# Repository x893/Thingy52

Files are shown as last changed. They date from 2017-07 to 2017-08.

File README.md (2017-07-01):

# Nordic Thingy:52 SDK

Welcome to the Nordic Thingy:52 software development kit.
This kit is designed to assist users in developing their own custom firmware for Thingy.
Please see http://www.nordicsemi.com/thingy for the latest news and software releases.

## Prerequisites

The simplest install is achieved by using one of the automated options below.
Before running the scripts, make sure you have the following software installed:
1. Python v2.7.xx or v3.xx.xx avaialble from https://www.python.org/. During the installation there will be a "Customize Python" window. Here, scroll to the bottom and select "Add python.exe to path." Otherwise, use default configurations.
2. Git v2.xx.xx, Available from https://git-scm.com/. Use default configurations.
3. Install GNU ARM embedded toolchain v4.9-2015q3. Avaialble from https://launchpad.net/gcc-arm-embedded/4.9/4.9-2015-q3-update. Use default configurations.
4. Make must be installed and be in system path.

## Setting up repository
### Windows
1. Run `setup_repo.bat`
2. Go to `project/pca20020_s132/armgcc/`
3. Run `make -j`

### Linux/Mac
1. Run `setup_repo.sh`
2. Go to `project/pca20020_s132/armgcc/`
3. Run `make -j`

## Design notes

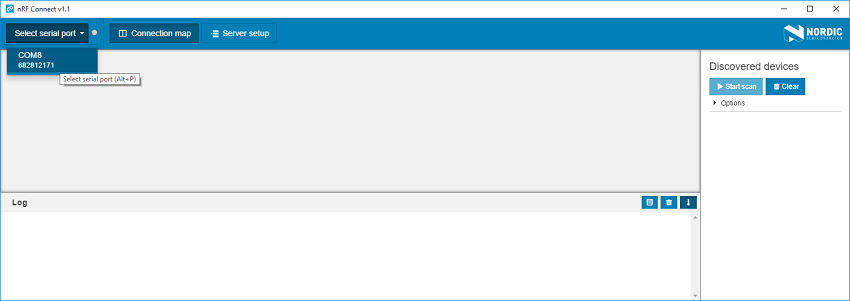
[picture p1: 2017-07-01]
source/doc/dox/pic/nrf_connect_d_1.png

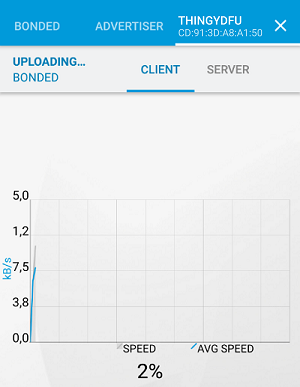
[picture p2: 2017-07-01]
source/doc/dox/pic/dfu_running.PNG

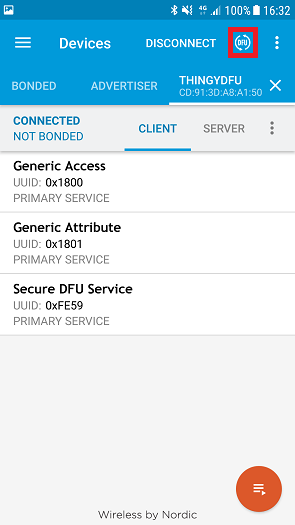
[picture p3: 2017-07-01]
source/doc/dox/pic/dfutarg_connect.png

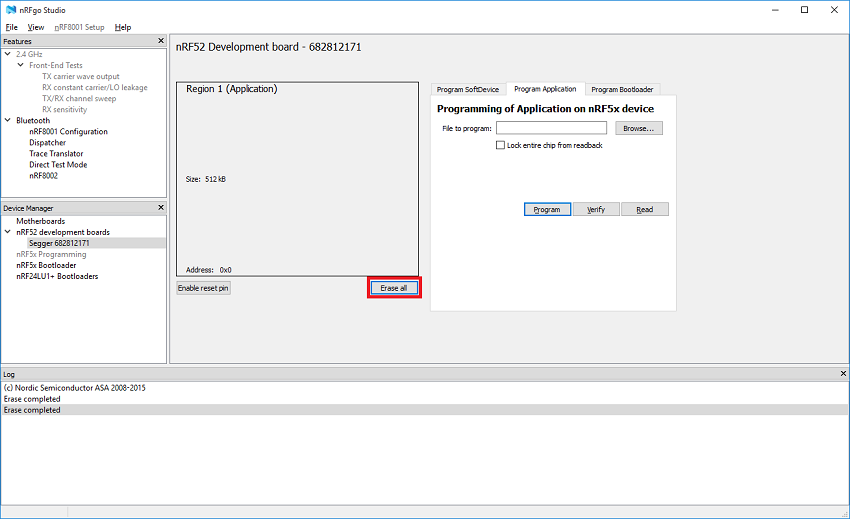
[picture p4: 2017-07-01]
source/doc/dox/pic/erase_all.png

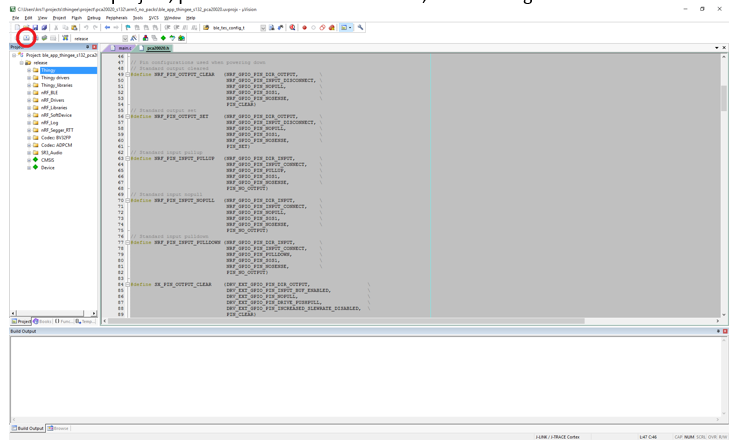
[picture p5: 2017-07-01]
source/doc/dox/pic/keil3.png

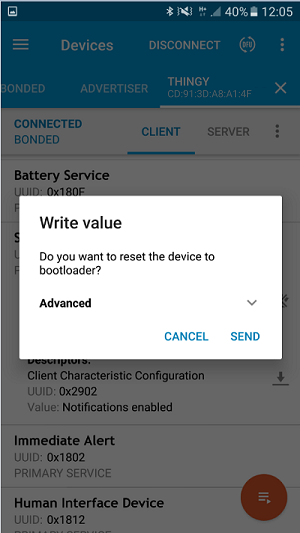
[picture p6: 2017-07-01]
source/doc/dox/pic/bootloader_reset.png

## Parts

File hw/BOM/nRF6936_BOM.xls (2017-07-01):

Bill of material
Kit: | nRF6936 - Thingy:52
Version: | 1.0.0
Designator | Value | Description | Manufacturer | Manufacturer Part Number
Design_1 | PCA20020 - Thingy:52 Board | Circuit board assembly
Design_2 | PCA64110 - NFC Listener-6 antenna | NFC antenna
Battery | Li-ion Polymer | Li-ion Polymer be 8 x 34.5 x 47 mm, 1500mAh | McNair NewPower Co.,Ltd | MLP793444 1440mAh 3.7V
Speaker | Speaker 15x11x3mm | Speaker, SMD, 15.0mm x 11.0mm x 3.0mm, 0Hz-20kHz, 89dB, 8 ohm, 0.7W | BeStar | BMS1511F-11C-08H03P LF

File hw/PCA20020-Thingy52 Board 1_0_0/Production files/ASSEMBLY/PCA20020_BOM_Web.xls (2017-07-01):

Bill of material
Board: | PCA20020
Version: | 1.0.0
Designator | Value | Description | Assembly | Footprint Doc | Manufacturer | Manufacturer Part Number
A1 | 2450AT18B100 | 2.45 GHz chip antenna |  | 2450AT18B100 | Johanson Technology | 2450AT18B100
C1, C2, C11, C12, C32, C33 | 12pF | Capacitor, NP0, ±2% |  | 0402
C3 | 0.8pF | Capacitor, NP0, ±5% |  | 0402
C4, C5, C8, C14, C15, C16, C17, C18, C20, C21, C23, C24, C25, C26, C27, C29, C34, C39 | 100nF | Capacitor, X7R, ±10% |  | 0402
C6 | N.C. | Not mounted | Not mounted | 0402
C7 | 100pF | Capacitor, NP0, ±5% |  | 0402
C9 | 4.7µF | Capacitor, X5R, ±10% |  | 0603
C10, C40, C41 | 1.0µF | Capacitor, X7R, ±10% |  | 0603
C13 | 2.2pF | Capacitor, NP0, ±0.1pF |  | 0402
C19, C30 | 10nF | Capacitor, X7R, ±10% |  | 0402
C22, C31, C38, C42, C44 | 10µF | Capacitor, X5R, ±20% |  | 0603
C28 | 1.0µF | Capacitor, X5R, ±5% |  | 0402
C35 | 150pF | Capacitor, NP0, ±5% |  | 0402
C36 | 330pF | Capacitor, NP0, ±5% |  | 0402
C37 | 220nF | Capacitor, X7R, ±10% |  | 0402
C43, C47 | 22µF | CAP CER 22UF 6.3V 20% X5R 0603 |  | 0603 | Samsung | CL10A226MQ8NRNC
C45, C46 | 270pF | Capacitor, NP0, ±5% |  | 0402
D1, D2 | Zener 2.4V | Diode, Zener, 2.4V, 0.3W |  | SOD-523 | Diodes Incorporated | BZT52C2V4T
FB1 | 600R/0.5A | Ferrite Bead, 600 Ohm @ 100MHz, 500mA, 380 mOhm Max |  | 0603 | Murata | BLM18AG601SN1
J1 | MicroUSB-B | MicroUSB-B-SMT |  | USB-Micro-B-RA-SMD-PiP | Allen Creations Corp. | AJU55-BS2111-L
J2 | HDR-2, 1mm | 1.0mm pitch connector side entry SMD |  | SM02B-SRSS-TB | JST | SM02B-SRSS-TB(LF)(SN)
J3 | FPC 0.5mm RA SMD | 0.5mm FPC, 5P,Right Angle SMT,Double Contact,H=1.2mm,White, Tin plated |  | FPC_05P-0.5mm-RA-SMD | W-CON | 5141-05RZDNWR01
L1, L4 | 3.9nH | Inductor, 170mA, ±0.1nH |  | 0402 | Murata | LQP15MN3N9B02D
L2 | 10µH | Inductor, 80mA, ±10% |  | 0603 | Taiyo Yuden | LBMF1608T100K
L3 | 15nH | Inductor, 320mA, ±5% |  | 0402 | Taiyo Yuden | HK100515NJ-T
L5 | N.C. | Not mounted | Not mounted | 0402
L6 | 220µH | Inductor, ±20%, 200mA, 2.76 Ohm |  | 4040 | Bourns | SRN4026-221M
LD1 | LED RGB | RGB LED 1.60 mm x 1.60 mm SMD |  | LED_RGB_0606 | Lite-On Inc | LTST-C19HE1WT
LD2, LD3 | LED RGB | High brightness, side view RGB LED |  | 6922 | ROHM | MSL0104RGBU1
P1, P2, P3 | Pin List 1x2 | Pin List 1x2, 2.54mm (100mil) | Not mounted | LIST_1x2
P4 | Pin Header 2x10 | Pin Header 2x10, 2.54mm (100mil) | Not mounted | HDR_2x10
P5, P6, P7, P8 | HW4-2.0 | 4 pin, Grove DIP connector | Not mounted | HW4-2.0 | Taifeng | HW4-2.0
P9 | Pin Header 2x5 | Pin Header 2x5, 1.27mm (50mil) |  | HDR_2x5-SMD-1.27mm-ANG | Samtec | FTSH-105-01-L-DH-A-C-TR
Q1, Q4, Q5 | DMC2400UV | Dual N & P Ch MOFET, 1.03A/0.7A, 480mOhm, 450mW |  | SOT-563 | Diodes Incorporated | DMC2400UV
Q2, Q3 | DMP2200UDW | Dual P Ch MOFET, 900mA, 260mOhm, 450mW |  | SOT-363 | Diodes Incorporated | DMP2200UDW
Q6, Q7 | DMN3190LDW | Dual N Ch MOFET, 1A, 190mOhm, 320mW |  | SOT-363 | Diodes Incorporated | DMN3190LDW
R1, R13, R15 | 10k | Resistor, ±1%, 0.063W |  | 0402
R2, R3 | 1M0 | Resistor, ±1%, 0.063W |  | 0402
R4, R7 | 169R | Resistor, ±1%, 0.063W |  | 0402
R5, R8 | 7R15 | Resistor, ±1%, 0.063W |  | 0402
R6, R9 | 11R | Resistor, ±1%, 0.063W |  | 0402
R10 | 100R | Resistor, ±1%, 0.063W |  | 0402
R11, R12 | 39R | Resistor, ±1%, 0.063W |  | 0402
R14, R16 | 18k | Resistor, ±1%, 0.063W |  | 0402
R17 | 27k | Resistor, ±1%, 0.063W |  | 0402
R18 | 15k | Resistor, ±1%, 0.063W |  | 0402
R19 | 10k | THERMISTOR 10K OHM NTC 0402 SMD |  | 0402 | Murata | NCP15XH103F03RC
R20 | 1M5 | Resistor, ±1%, 0.063W |  | 0402
R21 | 180k | Resistor, ±1%, 0.063W |  | 0402
R22, R23, R24, R25 | 4k7 | Resistor, ±1%, 0.063W |  | 0402
R27, R28 | 470R | Resistor, ±1%, 0.063W |  | 0402
R29, R30, R31 | 100k | Resistor, ±1%, 0.063W |  | 0402
SW1 | Switch | SMD slide Switch (ON-ON) |  | Switch-Slide-RA-J-Lead-DPDT-8.5x3.5mm | C&K Components | JS202011JAQN
SW2 | PB SW | Tactile Switch, SPNO, SMD, 160gf, 6.2x6.3x2.5mm |  | Switch-PB-6.2x6.3mm-SMD | Dailywell | TS604VM1-025BR-R
U1 | nRF52832-QFAAB0 | Multi-protocol Bluetooth Low Energy, ANT and 2.4GHz proprietary system-on-chip |  | QFN-48 | Nordic Semiconductor | nRF52832-QFAAB0
U2 | SX1509BIULTRT | IC GPIO EXPANDER I2C 16CH 28QFN |  | QFN-28 | Semtech Corporation | SX1509BIULTRT
U3 | MPU-9250 | 9-axis MotionTracking™ Device |  | QFN-24 | InvenSense | MPU-9250
U4, U10, U12 | NX3DV2567 | Low-ohmic four-pole double-throw analog switch |  | XQFN-16 | NXP Semiconductors | NX3DV2567GU
U5 | LIS2DH12 | 3-axis - ±2g/±4g/±8g/±16g digital output femto accelerometer |  | LGA-12 | STMicroelectronics | LIS2DH12
U6 | LPS22HB | MEMS nano pressure sensor: 260-1260 hPa absolute digital output barometer |  | HLGA-10L | STMicroelectronics | LPS22HB
U7 | HTS221 | Capacitive digital sensor for relative humidity and temperature |  | HLGA-6L | STMicroelectronics | HTS221
U8 | BH1745NUC | Digital 16bit Serial Output Type Color Sensor IC |  | WSON-8 | Rohm Semiconductor | BH1745NUC
U9 | CCS811 | Ultra-low power digital gas sensor for monitoring indoor air quality |  | LGA-10 | Cambridge CMOS Sensors | CCS811
U11 | MP34DB02 | MEMS audio sensor omnidirectional digital microphone |  | RHLGA-4 | STMicroelectronics | MP34DB02
U13, U15 | TCK106AF | 1.0 A Load Switch IC with Slew Rate Control Driver in Small Package |  | SOT-25 | Toshiba | TCK106AF,LF
U14 | XCL210C33 | 3.3V 200mA Inductor Built-in Step-Down “micro DC/DC” Converter |  | CL-2025 | Torex Semiconductor | XCL210C33
U16 | XC6804A4E1 | One Cell Li-ion/Li-polymer Linear Charger IC with Battery Temperature Detection |  | USP-6EL | Torex Semiconductor | XC6804A4E14R-G
X1 | 32MHz | XTAL SMD 2016, 32MHz, Cl=8pF, Tot: ±40ppm |  | XTAL_2016 | Kyocera | CX2016DB32000D0WZRC1
X2 | 32.768kHz | XTAL SMD 2012, 32.768kHz, 9pF, ±20ppm |  | XTAL_2012 | Micro Crystal | CM8V-T1A 32.768KHZ 9PF +/-20PPM TA QC

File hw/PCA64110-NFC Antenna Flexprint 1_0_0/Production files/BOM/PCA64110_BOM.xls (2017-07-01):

Bill of material
PCB: | PCA64110
Version: | 1.0.0
Designator | Value | Description | Footprint Doc | Manufacturer | Manufacturer Part Number

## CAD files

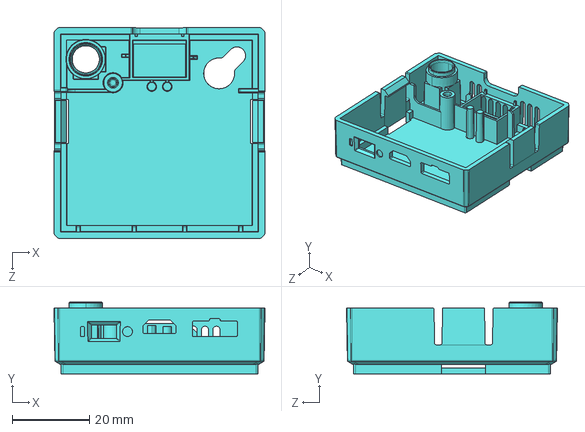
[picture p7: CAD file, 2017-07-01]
hw/CASING/Thingy52_Base.step
54.5 x 18.5 x 54.5 mm

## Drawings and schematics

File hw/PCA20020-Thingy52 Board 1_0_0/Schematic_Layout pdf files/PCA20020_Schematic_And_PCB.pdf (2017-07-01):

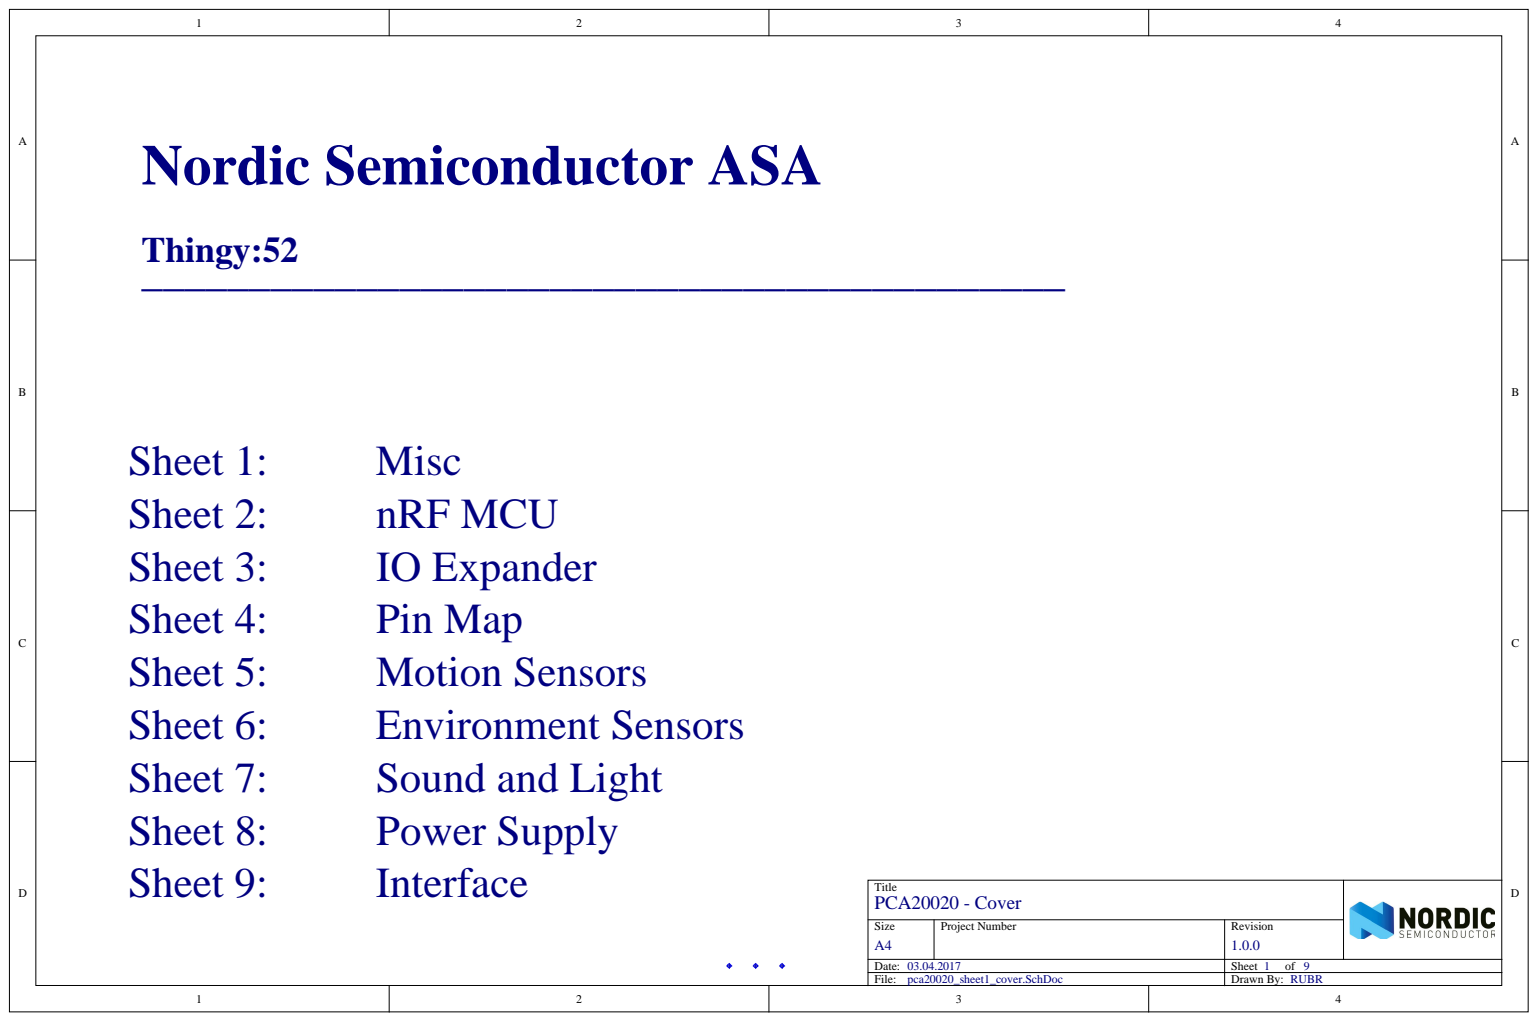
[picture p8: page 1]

Title PCA20020 - Cover

Size A4 | Project Number | Revision 1.0.0

Date: 03.04.2017 | Sheet of
File: pca20020_sheet1_cover.SchDoc | Drawn By: RUBR

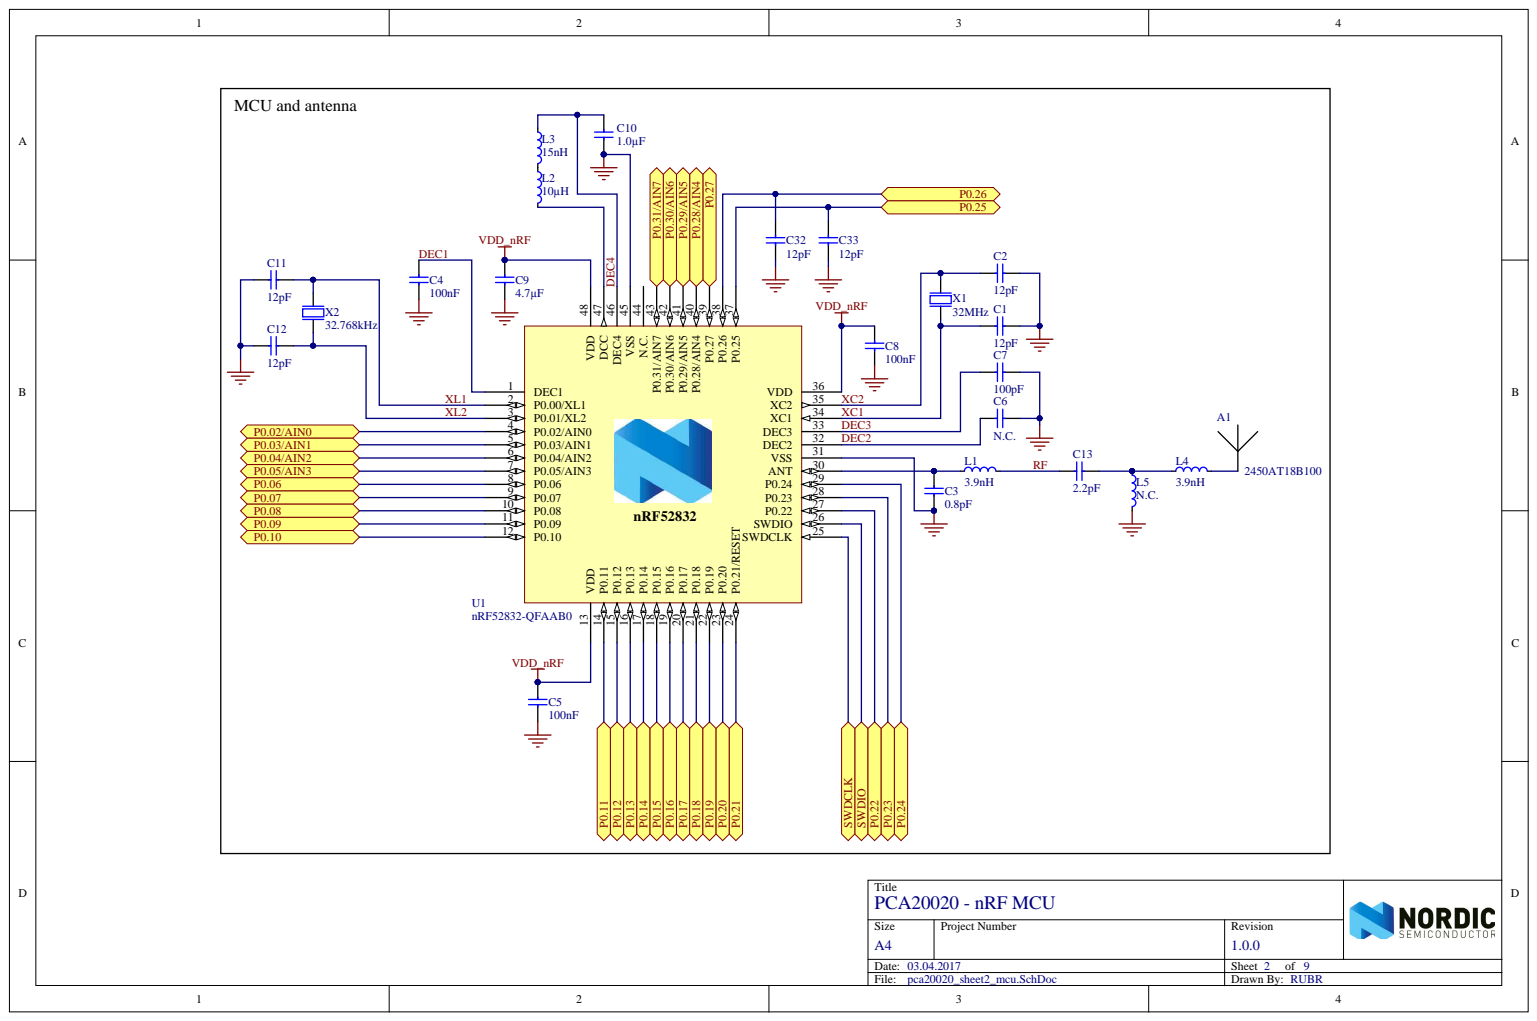
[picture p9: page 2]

P0.02/AIN0 4 P0.03/AIN1 5 P0.04/AIN2 6 P0.05/AIN3 7 P0.06 8 P0.07 9 P0.08 10 P0.09 11 P0.10 12 | DEC3

DEC2

Title PCA20020 - nRF MCU

Size A4 | Project Number | Revision 1.0.0

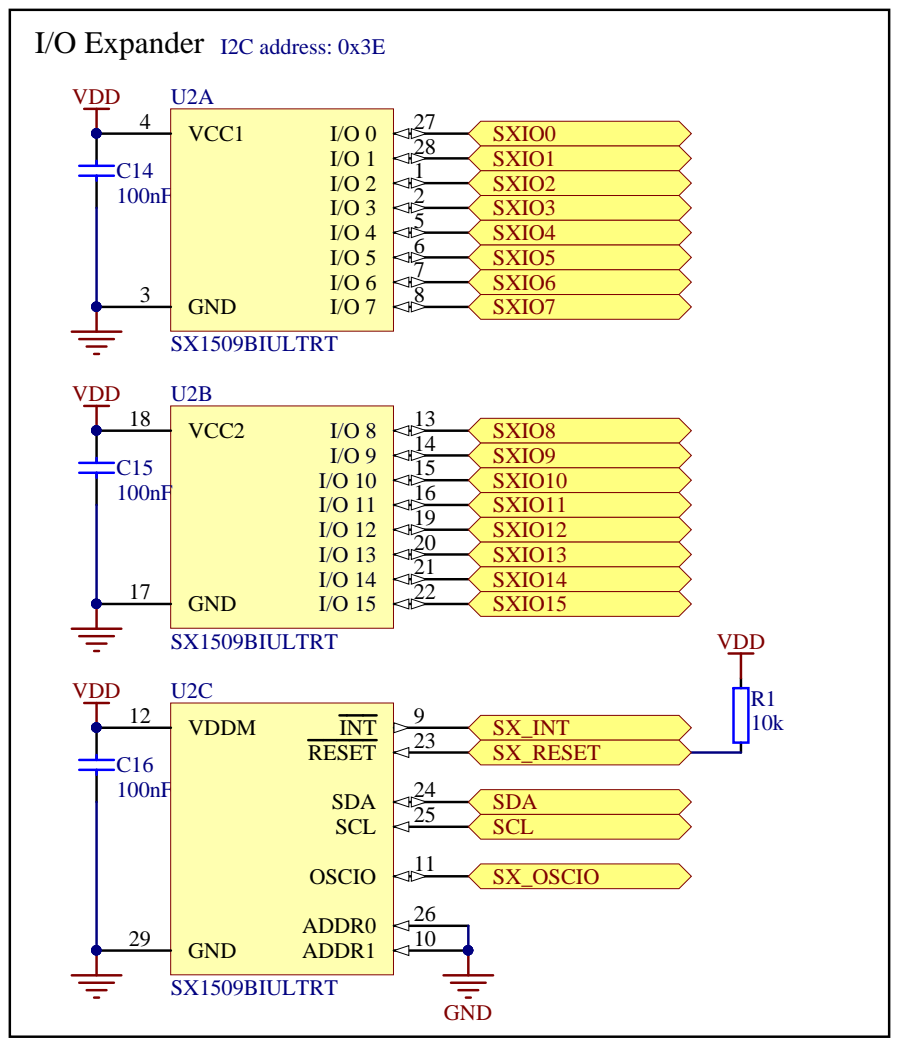
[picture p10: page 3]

Title PCA20020 - IO Expander

Size A4 | Project Number | Revision 1.0.0

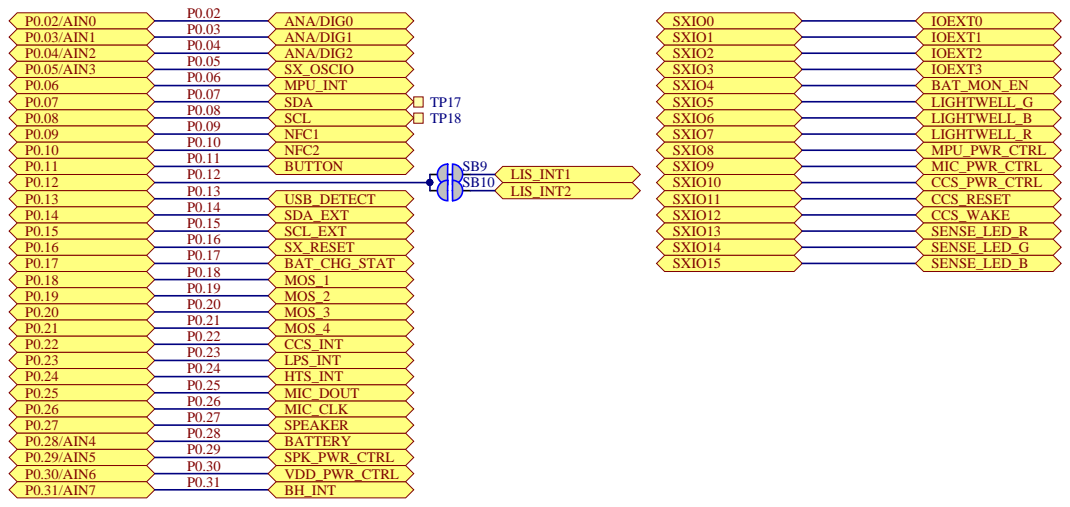
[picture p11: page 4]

Title PCA20020 - nRF Radio

Size A4 | Project Number | Revision 1.0.0

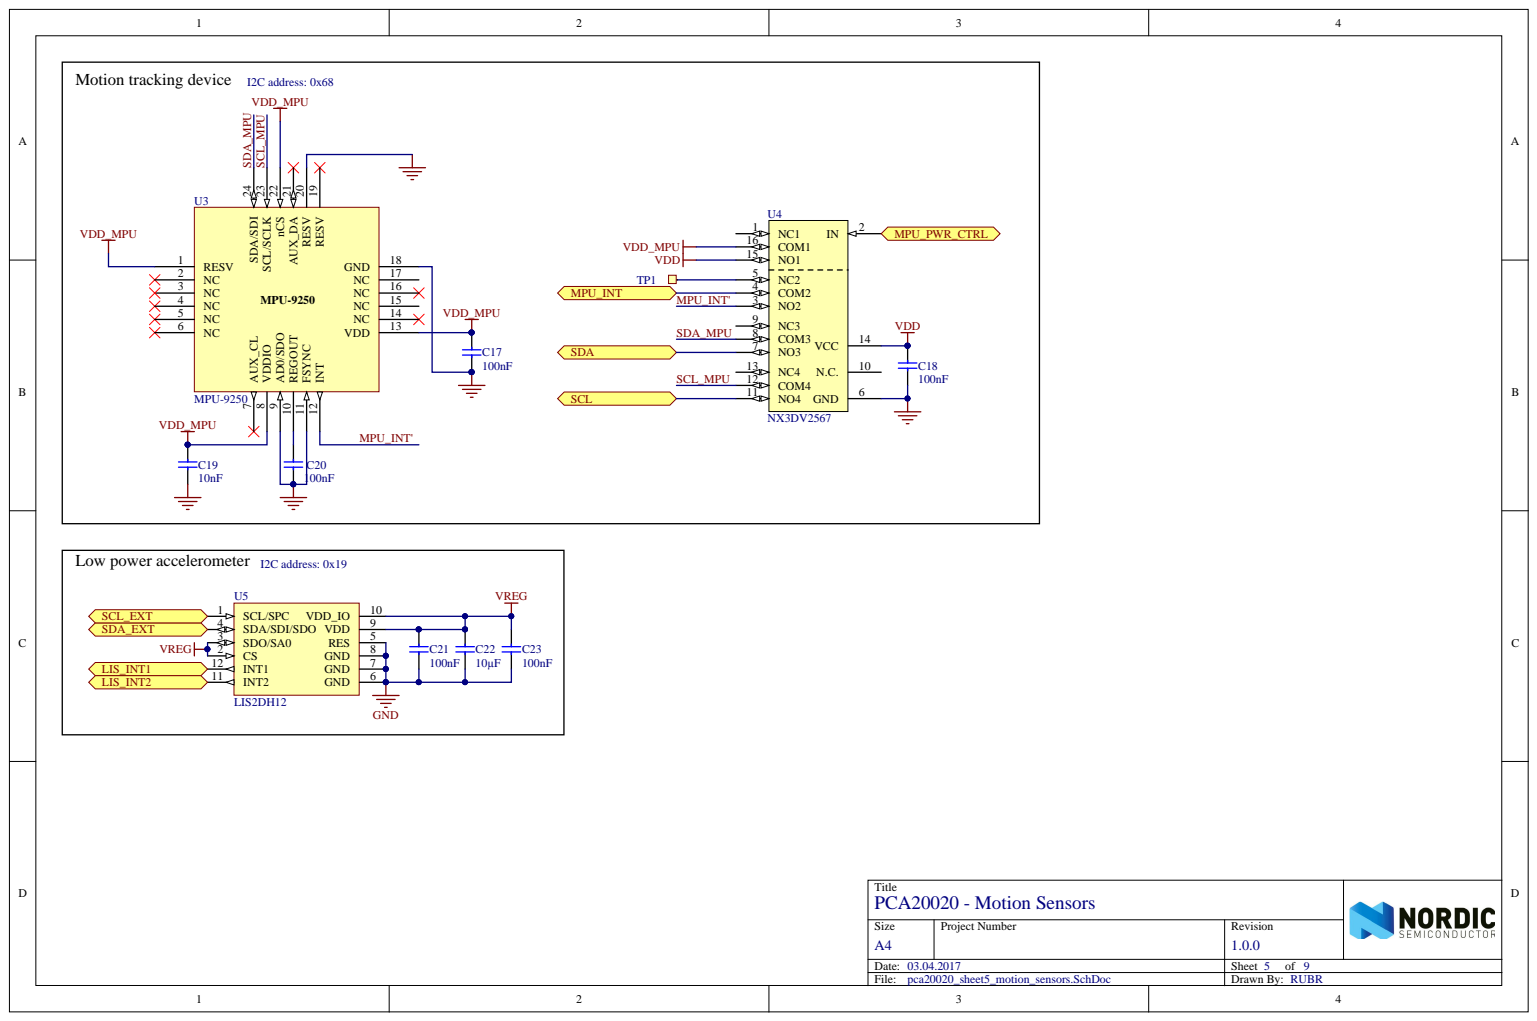
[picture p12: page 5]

Motion tracking device I2C address: 0x68

Title PCA20020 - Motion Sensors

Size A4 | Project Number | Revision 1.0.0

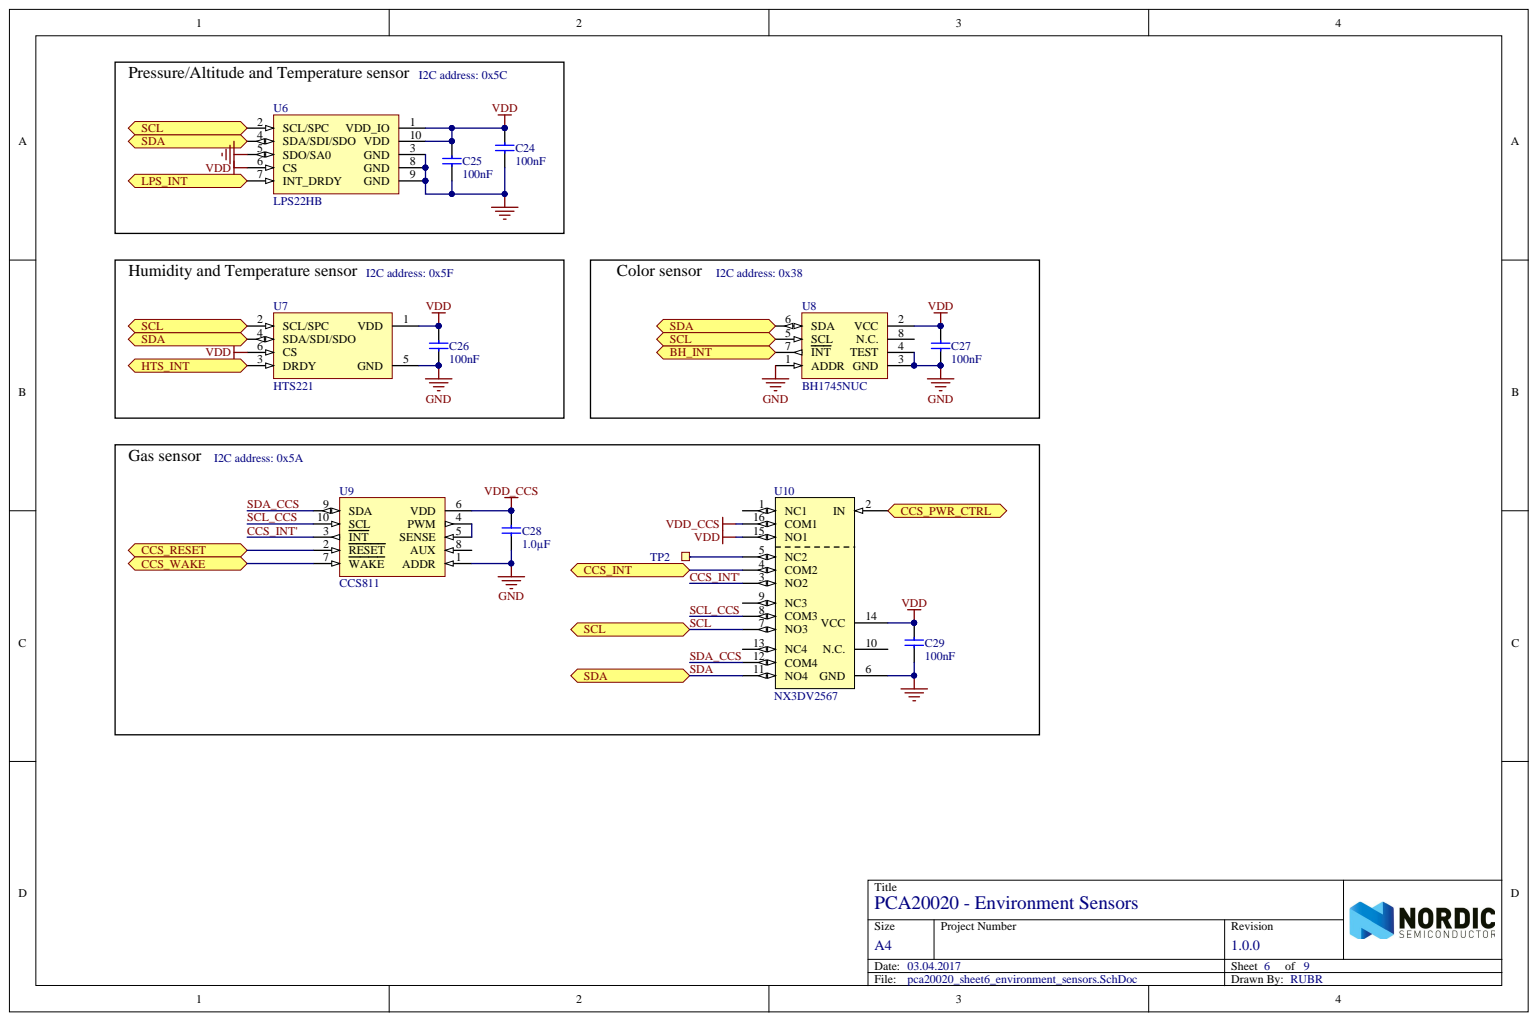
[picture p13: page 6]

Pressure/Altitude and Temperature sensor I2C address: 0x5C

Humidity and Temperature sensor I2C address: 0x5F

Title PCA20020 - Environment Sensors

Size A4 | Project Number | Revision 1.0.0

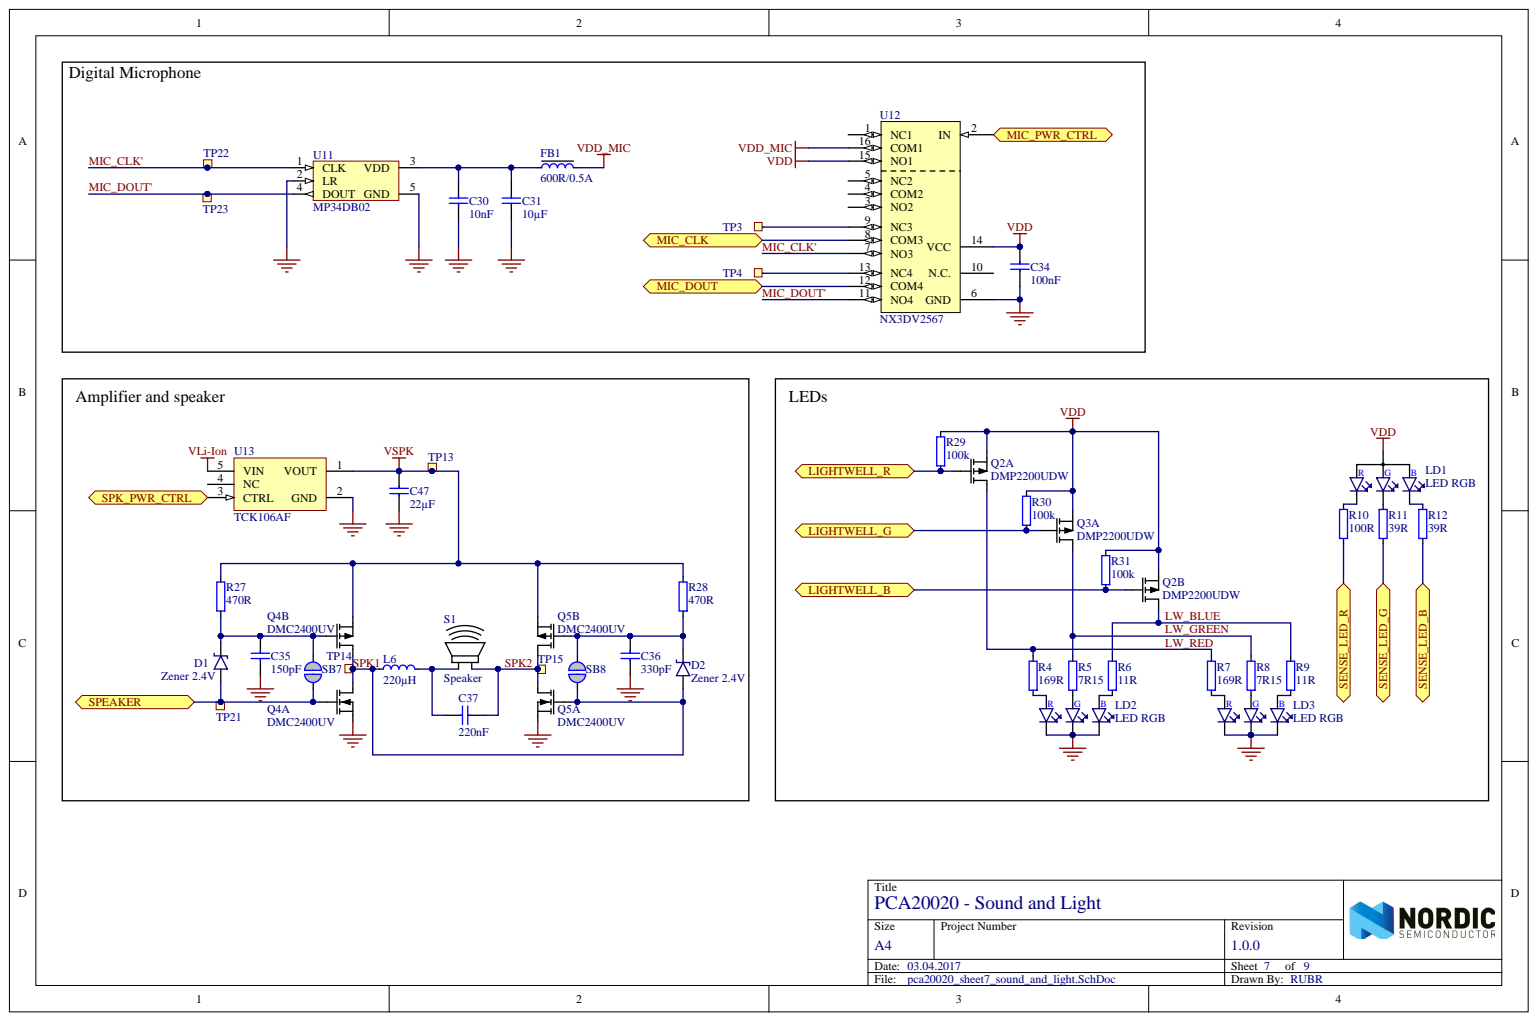
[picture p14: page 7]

LW_RED

LED RGB

Title PCA20020 - Sound and Light

Size A4 | Project Number | Revision 1.0.0

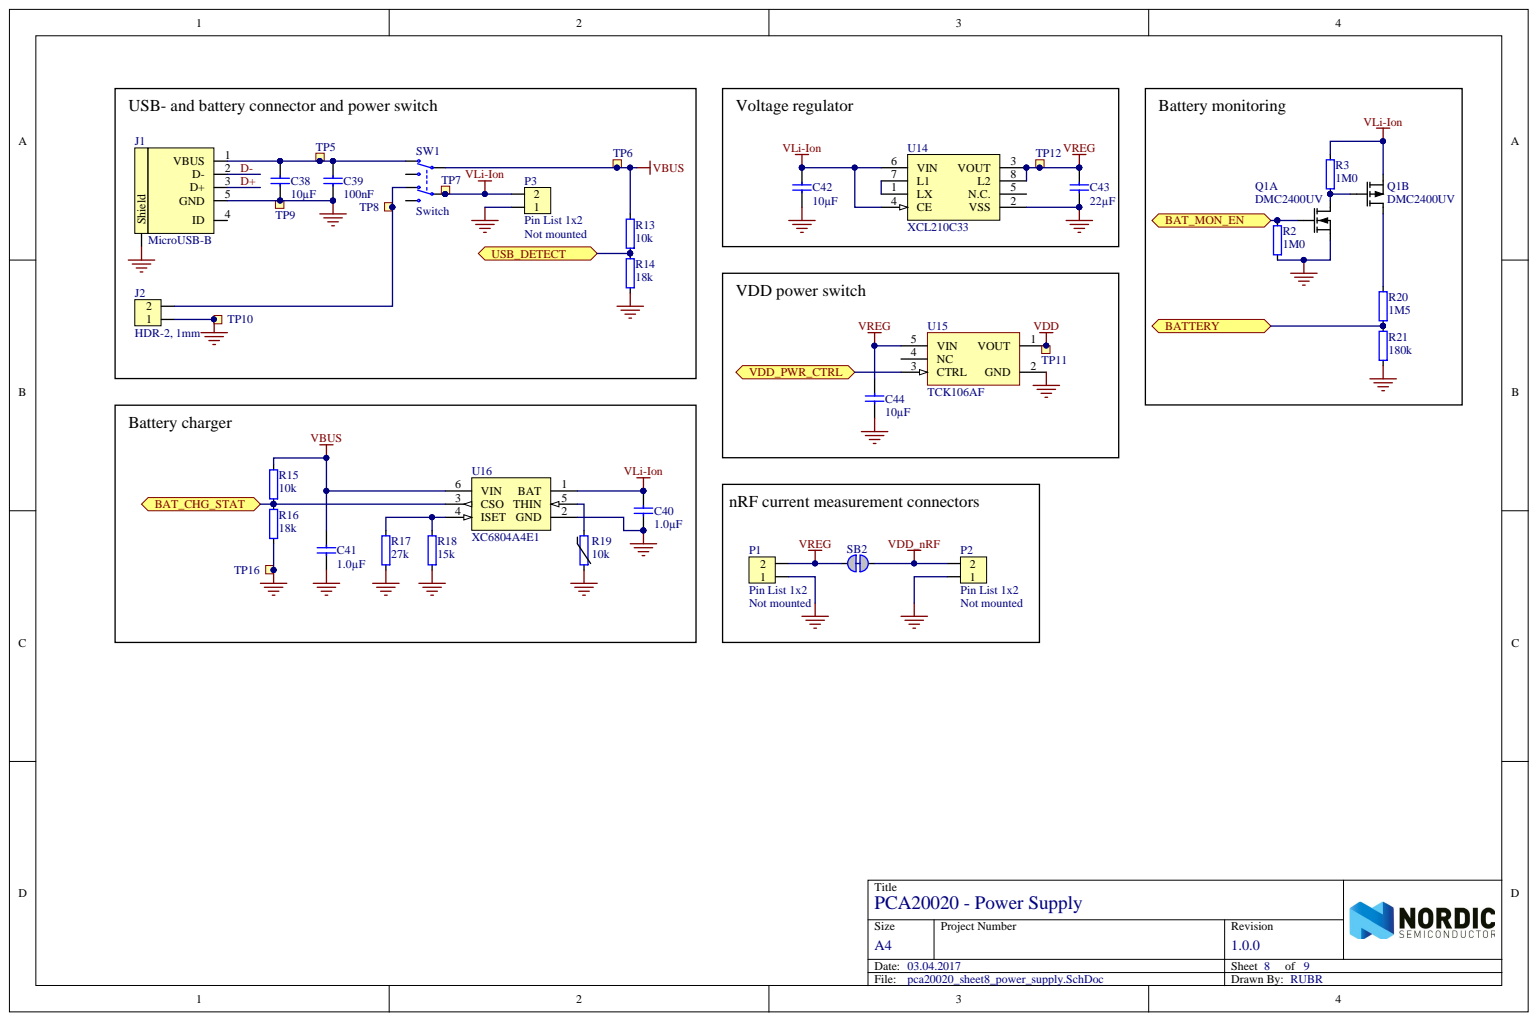
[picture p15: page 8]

USB- and battery connector and power switch

nRF current measurement connectors

Title PCA20020 - Power Supply

Size A4 | Project Number | Revision 1.0.0

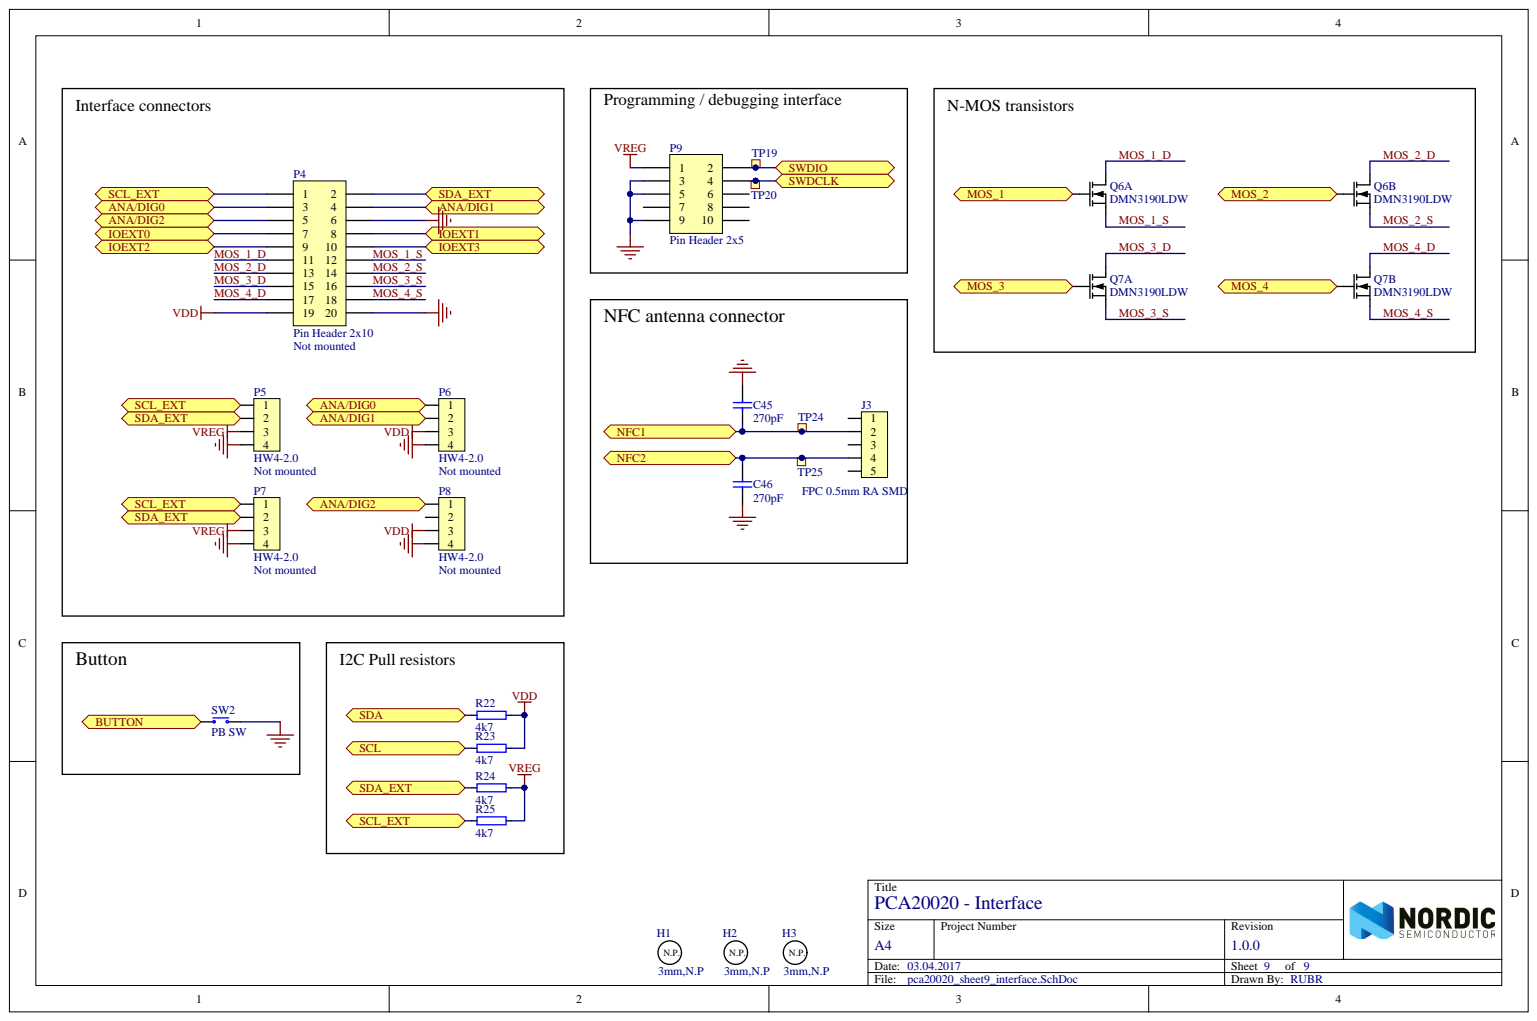
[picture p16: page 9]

Title PCA20020 - Interface

Size A4 | Project Number | Revision 1.0.0

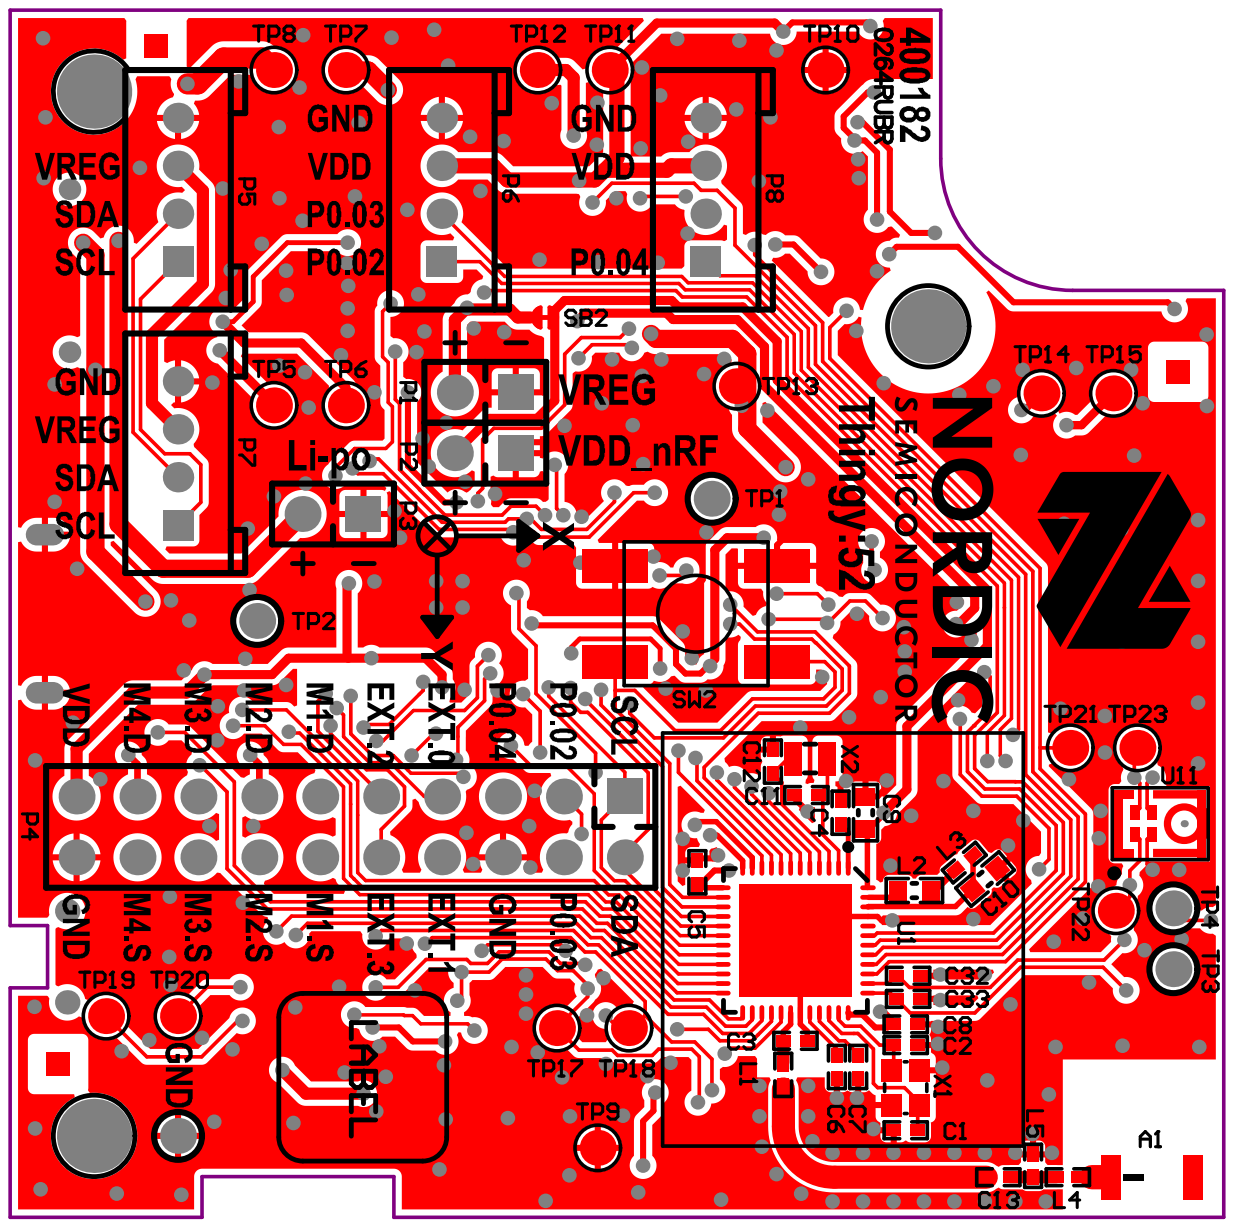
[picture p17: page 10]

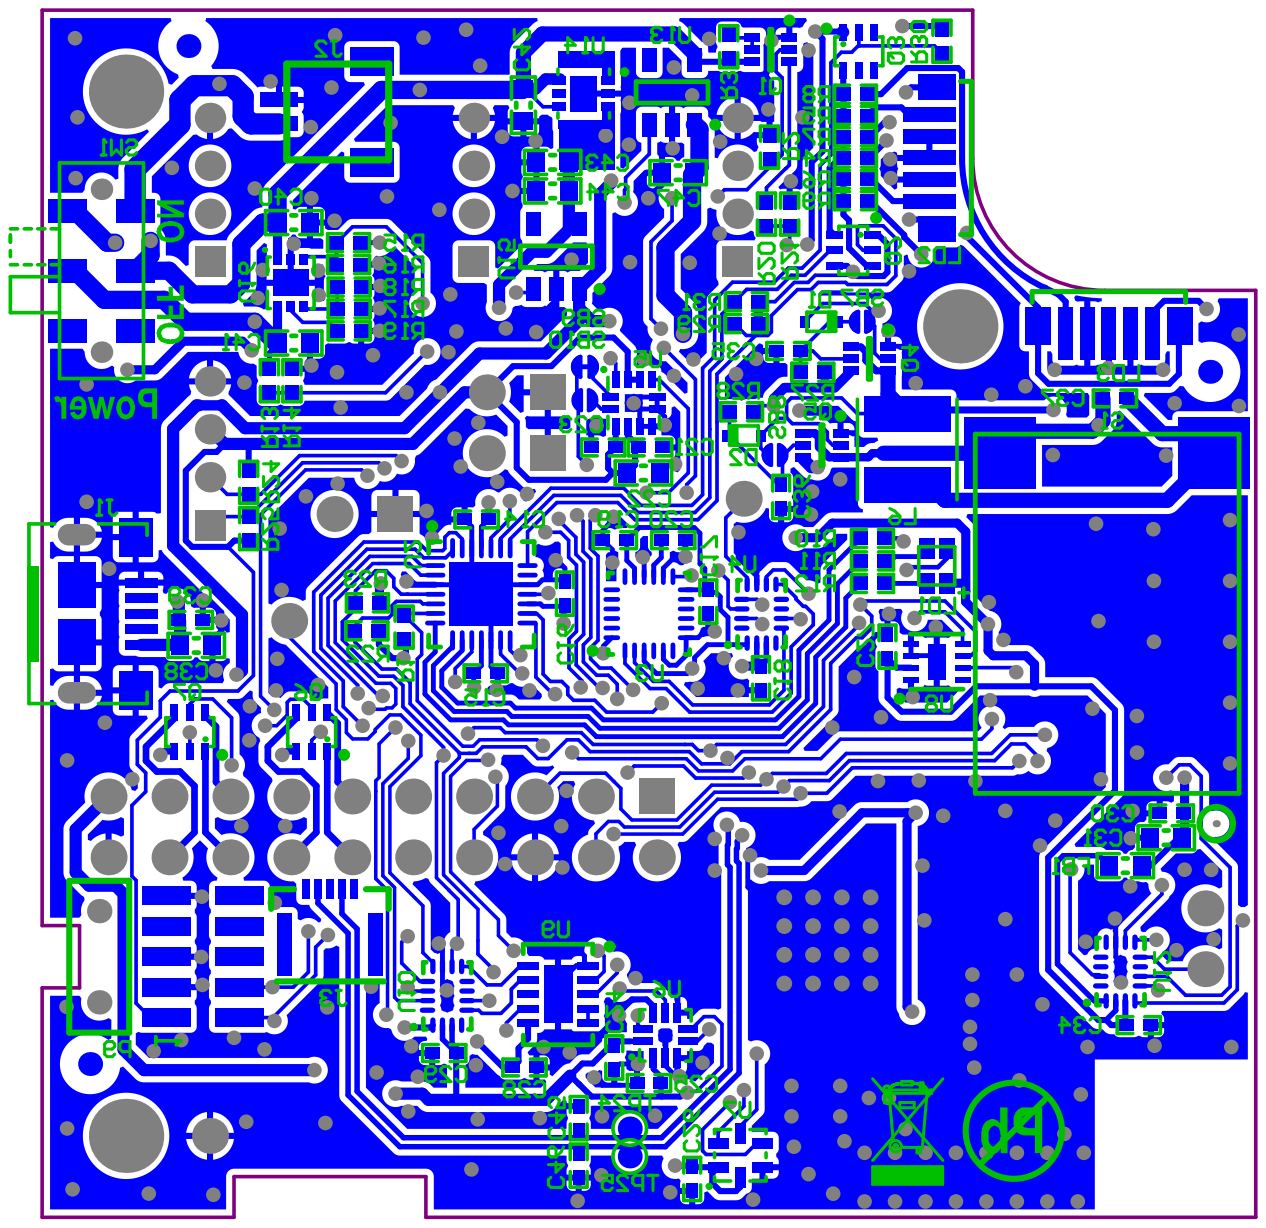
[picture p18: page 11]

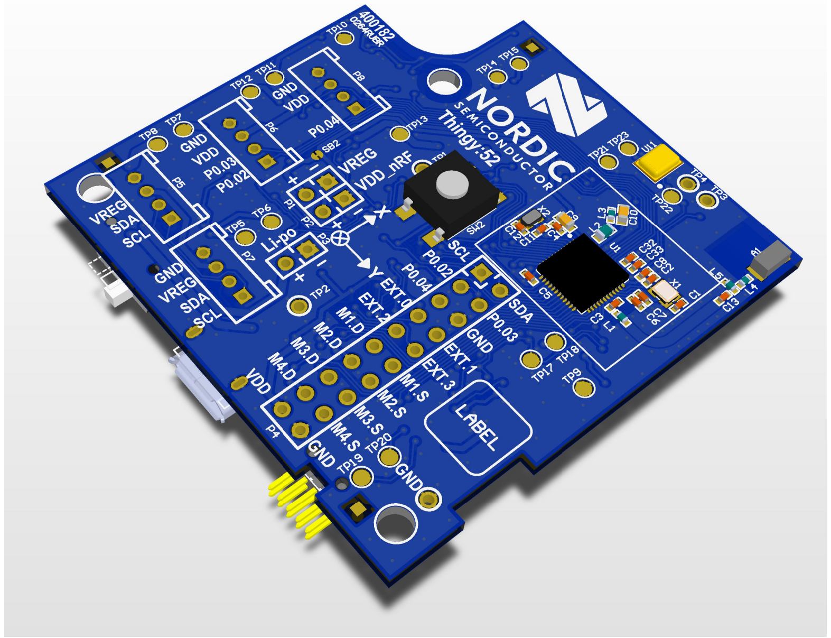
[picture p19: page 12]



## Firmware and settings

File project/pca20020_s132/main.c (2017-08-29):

/*
  Copyright (c) 2010 - 2017, Nordic Semiconductor ASA
  All rights reserved.

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
  1. Redistributions of source code must retain the above copyright notice, this
     list of conditions and the following disclaimer.

  2. Redistributions in binary form, except as embedded into a Nordic
     Semiconductor ASA integrated circuit in a product or a software update for
     such product, must reproduce the above copyright notice, this list of
     conditions and the following disclaimer in the documentation and/or other
     materials provided with the distribution.

  3. Neither the name of Nordic Semiconductor ASA nor the names of its
     contributors may be used to endorse or promote products derived from this
     software without specific prior written permission.

  4. This software, with or without modification, must only be used with a
     Nordic Semiconductor ASA integrated circuit.

  5. Any software provided in binary form under this license must not be reverse
     engineered, decompiled, modified and/or disassembled.

  THIS SOFTWARE IS PROVIDED BY NORDIC SEMICONDUCTOR ASA "AS IS" AND ANY EXPRESS
  OR IMPLIED WARRANTIES, INCLUDING, BUT NOT LIMITED TO, THE IMPLIED WARRANTIES
  OF MERCHANTABILITY, NONINFRINGEMENT, AND FITNESS FOR A PARTICULAR PURPOSE ARE
  DISCLAIMED. IN NO EVENT SHALL NORDIC SEMICONDUCTOR ASA OR CONTRIBUTORS BE
  LIABLE FOR ANY DIRECT, INDIRECT, INCIDENTAL, SPECIAL, EXEMPLARY, OR
  CONSEQUENTIAL DAMAGES (INCLUDING, BUT NOT LIMITED TO, PROCUREMENT OF SUBSTITUTE
  GOODS OR SERVICES; LOSS OF USE, DATA, OR PROFITS; OR BUSINESS INTERRUPTION)
  HOWEVER CAUSED AND ON ANY THEORY OF LIABILITY, WHETHER IN CONTRACT, STRICT
  LIABILITY, OR TORT (INCLUDING NEGLIGENCE OR OTHERWISE) ARISING IN ANY WAY OUT
  OF THE USE OF THIS SOFTWARE, EVEN IF ADVISED OF THE POSSIBILITY OF SUCH DAMAGE.
 */

/** @file
 *
 * @brief    Thingy application main file.
 *
 * This file contains the source code for the Thingy application that uses the Weather Station service.
 */

#include <stdint.h>
#include <float.h>
#include <string.h>
#include "nordic_common.h"
#include "nrf.h"
#include "ble_hci.h"
#include "ble_advdata.h"
#include "ble_advertising.h"
#include "ble_conn_params.h"
#include "softdevice_handler.h"
#include "app_timer_appsh.h"
#include "app_scheduler.h"
#include "app_button.h"
#include "app_util_platform.h"
#include "SEGGER_RTT.h"
#include "m_ble.h"
#include "m_environment.h"
#include "m_sound.h"
#include "m_motion.h"
#include "m_ui.h"
#include "m_batt_meas.h"
#include "drv_ext_light.h"
#include "drv_ext_gpio.h"
#include "nrf_delay.h"
#include "twi_manager.h"
#include "pca20020.h"
#include "app_error.h"
#include "support_func.h"

#define DEAD_BEEF   0xDEADBEEF          /**< Value used as error code on stack dump, can be used to identify stack location on stack unwind. */
#define SCHED_MAX_EVENT_DATA_SIZE   MAX(APP_TIMER_SCHED_EVT_SIZE, BLE_STACK_HANDLER_SCHED_EVT_SIZE) /**< Maximum size of scheduler events. */
#define SCHED_QUEUE_SIZE            60  /**< Maximum number of events in the scheduler queue. */

static const nrf_drv_twi_t     m_twi_sensors = NRF_DRV_TWI_INSTANCE(TWI_SENSOR_INSTANCE);
static m_ble_service_handle_t  m_ble_service_handles[THINGY_SERVICES_MAX];


void app_error_fault_handler(uint32_t id, uint32_t pc, uint32_t info)
{
    error_info_t * err_info = (error_info_t*)info;
    (void)SEGGER_RTT_printf(0, RTT_CTRL_TEXT_BRIGHT_RED"ASSERT: id = %d, pc = %d, file = %s, line number: %d, error code = %d \r\n"RTT_CTRL_RESET, \
    id, pc, err_info->p_file_name, err_info->line_num, err_info->err_code);

    (void)m_ui_led_set_event(M_UI_ERROR);
    nrf_delay_ms(100);
    // On assert, the system can only recover with a reset.
    #ifndef DEBUG
        NVIC_SystemReset();
    #endif

    app_error_save_and_stop(id, pc, info);
}


/**@brief Function for assert macro callback.
 *
 * @details This function will be called in case of an assert in the SoftDevice.
 *
 * @warning On assert from the SoftDevice, the system can only recover on reset.
 *
 * @param[in] line_num    Line number of the failing ASSERT call.
 * @param[in] p_file_name File name of the failing ASSERT call.
 */
void assert_nrf_callback(uint16_t line_num, const uint8_t * p_file_name)
{
    app_error_handler(DEAD_BEEF, line_num, p_file_name);
}

/**@brief Function for traversing all GPIOs for lowest power consumption.
 *
 * @param[in] vdd_on    If true, keep VDD turned on.
 */
static void configure_gpio_for_sleep(vdd_state_t vdd_on)
{
    ret_code_t err_code;

    sx_gpio_cfg_t  ioext_sys_off_pin_cfg[SX_IOEXT_NUM_PINS] = IOEXT_SYSTEM_OFF_PIN_CFG;

    nrf_gpio_cfg_t   nrf_sys_off_pin_cfg[NRF_NUM_GPIO_PINS] = NRF_SYSTEM_OFF_PIN_CFG;

    #if    defined(THINGY_HW_v0_7_0)
        // VDD always on.
    #elif  defined(THINGY_HW_v0_8_0)
        // VDD always on.
    #elif  defined(THINGY_HW_v0_9_0)
        // VDD always on.
    #else
        if (vdd_on)
        {
            nrf_sys_off_pin_cfg[VDD_PWR_CTRL] = (nrf_gpio_cfg_t)NRF_PIN_OUTPUT_SET;
        }
    #endif

    err_code = drv_ext_gpio_reset();
    APP_ERROR_CHECK(err_code);

    /* Set all IO extender pins in system off state. IO extender will be powered down as well,
    Hence, this config will not be retained when VDD is turned off. */
    for (uint8_t i = 0; i < SX_IOEXT_NUM_PINS; i++)
    {
        err_code = drv_ext_gpio_cfg(i,
                         ioext_sys_off_pin_cfg[i].dir,
                         ioext_sys_off_pin_cfg[i].input_buf,
                         ioext_sys_off_pin_cfg[i].pull_config,
                         ioext_sys_off_pin_cfg[i].drive_type,
                         ioext_sys_off_pin_cfg[i].slew_rate);
        APP_ERROR_CHECK(err_code);

        switch(ioext_sys_off_pin_cfg[i].state)
        {
            case PIN_CLEAR:
                err_code = drv_ext_gpio_pin_clear(i);
                APP_ERROR_CHECK(err_code);
                break;

            case PIN_SET:
                err_code = drv_ext_gpio_pin_set(i);
                APP_ERROR_CHECK(err_code);
                break;

            case PIN_NO_OUTPUT:
                err_code = NRF_SUCCESS;     // Do nothing.
                APP_ERROR_CHECK(err_code);
                break;

            default:
                err_code = NRF_ERROR_NOT_SUPPORTED;
        }
    }

    // Set all nRF pins in desired state for power off.
    for(uint8_t i = 0; i < NRF_NUM_GPIO_PINS; i++)
    {
        nrf_gpio_cfg(i,
                     nrf_sys_off_pin_cfg[i].dir,
                     nrf_sys_off_pin_cfg[i].input,
                     nrf_sys_off_pin_cfg[i].pull,
                     nrf_sys_off_pin_cfg[i].drive,
                     nrf_sys_off_pin_cfg[i].sense);

        switch(nrf_sys_off_pin_cfg[i].state)
        {
            case PIN_CLEAR:
                nrf_gpio_pin_clear(i);
                break;

            case PIN_SET:
                nrf_gpio_pin_set(i);
                break;

            case PIN_NO_OUTPUT:
                // Do nothing.
                break;

            default:
                APP_ERROR_CHECK(NRF_ERROR_NOT_SUPPORTED);
        }
    }
}


/**@brief Function for putting Thingy into sleep mode.
 *
 * @note This function will not return.
 */
static void sleep_mode_enter(void)
{
    uint32_t err_code;

    // Enable wake on button press.
    nrf_gpio_cfg_sense_input(BUTTON, NRF_GPIO_PIN_PULLUP, NRF_GPIO_PIN_SENSE_LOW);

    (void)SEGGER_RTT_printf(0, "Entering sleep mode \r\n");
    err_code = m_motion_sleep_prepare(true);
    APP_ERROR_CHECK(err_code);

    configure_gpio_for_sleep(VDD_OFF);

    // Enable wake on button press.
    nrf_gpio_cfg_sense_input(BUTTON, NRF_GPIO_PIN_PULLUP, NRF_GPIO_PIN_SENSE_LOW);
    // Enable wake on low power accelerometer.
    nrf_gpio_cfg_sense_input(LIS_INT1, NRF_GPIO_PIN_NOPULL, NRF_GPIO_PIN_SENSE_HIGH);

    // Go to system-off (sd_power_system_off() will not return; wakeup will cause a reset). When debugging, this function may return and code execution will continue.
    err_code = sd_power_system_off();
    (void)SEGGER_RTT_printf(0, "sd_power_system_off() returned. -Probably due to debugger being used. Instructions will still run. \r\n");

    #ifdef DEBUG
        if(!support_func_sys_halt_debug_enabled())
        {
            APP_ERROR_CHECK(err_code); // If not in debug mode, return the error and the system will reboot.
        }
        else
        {
            (void)SEGGER_RTT_printf(0, "Exec stopped, busy wait \r\n");
            while(true) // Only reachable when entering emulated system off.
            {
                // Infinte loop to ensure that code stops in debug mode.
            }
        }
    #else
        APP_ERROR_CHECK(err_code);
    #endif
}


/**@brief Function for placing the application in low power state while waiting for events.
 */
#define FPU_EXCEPTION_MASK 0x0000009F
static void power_manage(void)
{
    __set_FPSCR(__get_FPSCR()  & ~(FPU_EXCEPTION_MASK));
    (void) __get_FPSCR();
    NVIC_ClearPendingIRQ(FPU_IRQn);

    uint32_t err_code = sd_app_evt_wait();
    APP_ERROR_CHECK(err_code);
}


/**@brief Battery module data handler.
 */
static void m_batt_meas_handler(m_batt_meas_event_t const * p_batt_meas_event)
{
    (void)SEGGER_RTT_printf(0, "batt meas handler: Voltage: %d V, Charge: %d %%, Event type: %d \n",
        p_batt_meas_event->voltage_mv, p_batt_meas_event->level_percent, p_batt_meas_event->type);

    if (p_batt_meas_event != NULL)
    {
        if( p_batt_meas_event->type == M_BATT_MEAS_EVENT_LOW)
        {
            uint32_t err_code;
            configure_gpio_for_sleep(VDD_OFF);

            // Enable wake on USB detect only.
            nrf_gpio_cfg_sense_input(USB_DETECT, NRF_GPIO_PIN_NOPULL, NRF_GPIO_PIN_SENSE_HIGH);

            (void)SEGGER_RTT_printf(0, RTT_CTRL_TEXT_BRIGHT_YELLOW"Battery voltage low, shutting down Thingy. Connect USB to charge. "RTT_CTRL_RESET"\n");
            // Go to system-off mode (This function will not return; wakeup will cause a reset).
            err_code = sd_power_system_off();

            #ifdef DEBUG
                if(!support_func_sys_halt_debug_enabled())
                {
                    APP_ERROR_CHECK(err_code); // If not in debug mode, return the error and the system will reboot.
                }
                else
                {
                    (void)SEGGER_RTT_printf(0, "Exec stopped, busy wait \r\n");
                    while(true) // Only reachable when entering emulated system off.
                    {
                        // Infinte loop to ensure that code stops in debug mode.
                    }
                }
            #else
                APP_ERROR_CHECK(err_code);
            #endif
        }
    }
}


/**@brief Function for handling BLE events.
 */
static void thingy_ble_evt_handler(m_ble_evt_t * p_evt)
{
    switch (p_evt->evt_type)
    {
        case thingy_ble_evt_connected:
            (void)SEGGER_RTT_WriteString(0, RTT_CTRL_TEXT_BRIGHT_GREEN"Thingy_ble_evt_connected"RTT_CTRL_RESET"\n");
            break;

        case thingy_ble_evt_disconnected:
            (void)SEGGER_RTT_WriteString(0, RTT_CTRL_TEXT_BRIGHT_GREEN"Thingy_ble_evt_disconnected"RTT_CTRL_RESET"\n");
            nrf_delay_ms(5);
            NVIC_SystemReset();
            break;

        case thingy_ble_evt_timeout:
            (void)SEGGER_RTT_WriteString(0, RTT_CTRL_TEXT_BRIGHT_GREEN"Thingy_ble_evt_timeout"RTT_CTRL_RESET"\n");
            nrf_delay_ms(5);
            sleep_mode_enter();
            NVIC_SystemReset();
            break;
    }
}


/**@brief Function for initializing the Thingy.
 */
static void thingy_init(void)
{
    uint32_t                 err_code;
    m_ui_init_t              ui_params;
    m_environment_init_t     env_params;
    m_motion_init_t          motion_params;
    m_ble_init_t             ble_params;
    batt_meas_init_t         batt_meas_init = BATT_MEAS_PARAM_CFG;

    /**@brief Initialize the TWI manager. */
    err_code = twi_manager_init(APP_IRQ_PRIORITY_THREAD);
    APP_ERROR_CHECK(err_code);

    /**@brief Initialize LED and button UI module. */
    ui_params.p_twi_instance = &m_twi_sensors;
    err_code = m_ui_init(&m_ble_service_handles[THINGY_SERVICE_UI],
                         &ui_params);
    APP_ERROR_CHECK(err_code);

    /**@brief Initialize environment module. */
    env_params.p_twi_instance = &m_twi_sensors;
    err_code = m_environment_init(&m_ble_service_handles[THINGY_SERVICE_ENVIRONMENT],
                                  &env_params);
    APP_ERROR_CHECK(err_code);

    /**@brief Initialize motion module. */
    motion_params.p_twi_instance = &m_twi_sensors;

    err_code = m_motion_init(&m_ble_service_handles[THINGY_SERVICE_MOTION],
                             &motion_params);
    APP_ERROR_CHECK(err_code);

#if CONFIG_AUDIO_ENABLED
    err_code = m_sound_init(&m_ble_service_handles[THINGY_SERVICE_SOUND]);
    APP_ERROR_CHECK(err_code);
#endif

    /**@brief Initialize the battery measurement. */
    batt_meas_init.evt_handler = m_batt_meas_handler;
    err_code = m_batt_meas_init(&m_ble_service_handles[THINGY_SERVICE_BATTERY], &batt_meas_init);
    APP_ERROR_CHECK(err_code);

    err_code = m_batt_meas_enable(BATT_MEAS_INTERVAL_MS);
    APP_ERROR_CHECK(err_code);

    /**@brief Initialize BLE handling module. */
    ble_params.evt_handler       = thingy_ble_evt_handler;
    ble_params.p_service_handles = m_ble_service_handles;
    ble_params.service_num       = 5;

    err_code = m_ble_init(&ble_params);
    APP_ERROR_CHECK(err_code);

    err_code = m_ui_led_set_event(M_UI_BLE_DISCONNECTED);
    APP_ERROR_CHECK(err_code);
    
    err_code = support_func_ble_mac_address_print_rtt();
    APP_ERROR_CHECK(err_code);
}


static void board_init(void)
{
    uint32_t            err_code;
    drv_ext_gpio_init_t ext_gpio_init;

    #if defined(THINGY_HW_v0_7_0)
        #error   "HW version v0.7.0 not supported."
    #elif defined(THINGY_HW_v0_8_0)
        (void)SEGGER_RTT_WriteString(0, RTT_CTRL_TEXT_BRIGHT_YELLOW"FW compiled for depricated Thingy HW v0.8.0"RTT_CTRL_RESET"\n");
    #elif defined(THINGY_HW_v0_9_0)
        (void)SEGGER_RTT_WriteString(0, RTT_CTRL_TEXT_BRIGHT_YELLOW"FW compiled for depricated Thingy HW v0.9.0"RTT_CTRL_RESET"\n");
    #endif

    /**@brief Enable power on VDD. */
    nrf_gpio_cfg_output(VDD_PWR_CTRL);
    nrf_gpio_pin_set(VDD_PWR_CTRL);

    nrf_delay_ms(75);

    static const nrf_drv_twi_config_t twi_config =
    {
        .scl                = TWI_SCL,
        .sda                = TWI_SDA,
        .frequency          = NRF_TWI_FREQ_400K,
        .interrupt_priority = APP_IRQ_PRIORITY_LOW
    };

    static const drv_sx1509_cfg_t sx1509_cfg =
    {
        .twi_addr       = SX1509_ADDR,
        .p_twi_instance = &m_twi_sensors,
        .p_twi_cfg      = &twi_config
    };

    ext_gpio_init.p_cfg = &sx1509_cfg;

    err_code = drv_ext_gpio_init(&ext_gpio_init, true);
    APP_ERROR_CHECK(err_code);

    configure_gpio_for_sleep(VDD_ON);    // Set all pins to their default state, with the exception of VDD_PWR_CTRL.

    err_code = drv_ext_gpio_cfg_output(SX_LIGHTWELL_R);
    APP_ERROR_CHECK(err_code);
    err_code = drv_ext_gpio_cfg_output(SX_LIGHTWELL_G);
    APP_ERROR_CHECK(err_code);
    err_code = drv_ext_gpio_cfg_output(SX_LIGHTWELL_B);
    APP_ERROR_CHECK(err_code);
    err_code = drv_ext_gpio_pin_set(SX_LIGHTWELL_R);
    APP_ERROR_CHECK(err_code);
    err_code = drv_ext_gpio_pin_set(SX_LIGHTWELL_G);
    APP_ERROR_CHECK(err_code);
    err_code = drv_ext_gpio_pin_set(SX_LIGHTWELL_B);
    APP_ERROR_CHECK(err_code);

    #if defined(THINGY_HW_v0_8_0)
        nrf_gpio_cfg_output(VOLUME);
        nrf_gpio_pin_clear(VOLUME);

        err_code = drv_ext_gpio_cfg_output(SX_SPK_PWR_CTRL);
        APP_ERROR_CHECK(err_code);

        err_code = drv_ext_gpio_pin_clear(SX_SPK_PWR_CTRL);
        APP_ERROR_CHECK(err_code);
    #else
        nrf_gpio_cfg_output(SPK_PWR_CTRL);
        nrf_gpio_pin_clear(SPK_PWR_CTRL);
    #endif

    nrf_delay_ms(100);
}


/**@brief Application main function.
 */
int main(void)
{
    (void)SEGGER_RTT_WriteString(0, RTT_CTRL_TEXT_BRIGHT_GREEN"===== Start!! ====="RTT_CTRL_RESET"\n");

    // Initialize.
    APP_SCHED_INIT(SCHED_MAX_EVENT_DATA_SIZE, SCHED_QUEUE_SIZE);
    APP_TIMER_APPSH_INIT(APP_TIMER_PRESCALER, APP_TIMER_OP_QUEUE_SIZE, true);

    board_init();
    thingy_init();

    for (;;)
    {
        app_sched_execute();
        power_manage();
    }
}

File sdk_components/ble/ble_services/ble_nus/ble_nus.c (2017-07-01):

/* Copyright (c) 2012 Nordic Semiconductor. All Rights Reserved.
 *
 * The information contained herein is property of Nordic Semiconductor ASA.
 * Terms and conditions of usage are described in detail in NORDIC
 * SEMICONDUCTOR STANDARD SOFTWARE LICENSE AGREEMENT.
 *
 * Licensees are granted free, non-transferable use of the information. NO
 * WARRANTY of ANY KIND is provided. This heading must NOT be removed from
 * the file.
 *
 */
#include "sdk_config.h"
#if BLE_NUS_ENABLED
#include "ble_nus.h"
#include "ble_srv_common.h"
#include "sdk_common.h"

#define BLE_UUID_NUS_TX_CHARACTERISTIC 0x0002                      /**< The UUID of the TX Characteristic. */
#define BLE_UUID_NUS_RX_CHARACTERISTIC 0x0003                      /**< The UUID of the RX Characteristic. */

#define BLE_NUS_MAX_RX_CHAR_LEN        BLE_NUS_MAX_DATA_LEN        /**< Maximum length of the RX Characteristic (in bytes). */
#define BLE_NUS_MAX_TX_CHAR_LEN        BLE_NUS_MAX_DATA_LEN        /**< Maximum length of the TX Characteristic (in bytes). */

#define NUS_BASE_UUID                  {{0x9E, 0xCA, 0xDC, 0x24, 0x0E, 0xE5, 0xA9, 0xE0, 0x93, 0xF3, 0xA3, 0xB5, 0x00, 0x00, 0x40, 0x6E}} /**< Used vendor specific UUID. */

/**@brief Function for handling the @ref BLE_GAP_EVT_CONNECTED event from the S110 SoftDevice.
 *
 * @param[in] p_nus     Nordic UART Service structure.
 * @param[in] p_ble_evt Pointer to the event received from BLE stack.
 */
static void on_connect(ble_nus_t * p_nus, ble_evt_t * p_ble_evt)
{
    p_nus->conn_handle = p_ble_evt->evt.gap_evt.conn_handle;
}


/**@brief Function for handling the @ref BLE_GAP_EVT_DISCONNECTED event from the S110 SoftDevice.
 *
 * @param[in] p_nus     Nordic UART Service structure.
 * @param[in] p_ble_evt Pointer to the event received from BLE stack.
 */
static void on_disconnect(ble_nus_t * p_nus, ble_evt_t * p_ble_evt)
{
    UNUSED_PARAMETER(p_ble_evt);
    p_nus->conn_handle = BLE_CONN_HANDLE_INVALID;
}


/**@brief Function for handling the @ref BLE_GATTS_EVT_WRITE event from the S110 SoftDevice.
 *
 * @param[in] p_nus     Nordic UART Service structure.
 * @param[in] p_ble_evt Pointer to the event received from BLE stack.
 */
static void on_write(ble_nus_t * p_nus, ble_evt_t * p_ble_evt)
{
    ble_gatts_evt_write_t * p_evt_write = &p_ble_evt->evt.gatts_evt.params.write;

    if (
        (p_evt_write->handle == p_nus->rx_handles.cccd_handle)
        &&
        (p_evt_write->len == 2)
       )
    {
        if (ble_srv_is_notification_enabled(p_evt_write->data))
        {
            p_nus->is_notification_enabled = true;
        }
        else
        {
            p_nus->is_notification_enabled = false;
        }
    }
    else if (
             (p_evt_write->handle == p_nus->tx_handles.value_handle)
             &&
             (p_nus->data_handler != NULL)
            )
    {
        p_nus->data_handler(p_nus, p_evt_write->data, p_evt_write->len);
    }
    else
    {
        // Do Nothing. This event is not relevant for this service.
    }
}


/**@brief Function for adding RX characteristic.
 *
 * @param[in] p_nus       Nordic UART Service structure.
 * @param[in] p_nus_init  Information needed to initialize the service.
 *
 * @return NRF_SUCCESS on success, otherwise an error code.
 */
static uint32_t rx_char_add(ble_nus_t * p_nus, const ble_nus_init_t * p_nus_init)
{
    /**@snippet [Adding proprietary characteristic to S110 SoftDevice] */
    ble_gatts_char_md_t char_md;
    ble_gatts_attr_md_t cccd_md;
    ble_gatts_attr_t    attr_char_value;
    ble_uuid_t          ble_uuid;
    ble_gatts_attr_md_t attr_md;

    memset(&cccd_md, 0, sizeof(cccd_md));

    BLE_GAP_CONN_SEC_MODE_SET_OPEN(&cccd_md.read_perm);
    BLE_GAP_CONN_SEC_MODE_SET_OPEN(&cccd_md.write_perm);

    cccd_md.vloc = BLE_GATTS_VLOC_STACK;

    memset(&char_md, 0, sizeof(char_md));

    char_md.char_props.notify = 1;
    char_md.p_char_user_desc  = NULL;
    char_md.p_char_pf         = NULL;
    char_md.p_user_desc_md    = NULL;
    char_md.p_cccd_md         = &cccd_md;
    char_md.p_sccd_md         = NULL;

    ble_uuid.type = p_nus->uuid_type;
    ble_uuid.uuid = BLE_UUID_NUS_RX_CHARACTERISTIC;

    memset(&attr_md, 0, sizeof(attr_md));

    BLE_GAP_CONN_SEC_MODE_SET_OPEN(&attr_md.read_perm);
    BLE_GAP_CONN_SEC_MODE_SET_OPEN(&attr_md.write_perm);

    attr_md.vloc    = BLE_GATTS_VLOC_STACK;
    attr_md.rd_auth = 0;
    attr_md.wr_auth = 0;
    attr_md.vlen    = 1;

    memset(&attr_char_value, 0, sizeof(attr_char_value));

    attr_char_value.p_uuid    = &ble_uuid;
    attr_char_value.p_attr_md = &attr_md;
    attr_char_value.init_len  = sizeof(uint8_t);
    attr_char_value.init_offs = 0;
    attr_char_value.max_len   = BLE_NUS_MAX_RX_CHAR_LEN;

    return sd_ble_gatts_characteristic_add(p_nus->service_handle,
                                           &char_md,
                                           &attr_char_value,
                                           &p_nus->rx_handles);
    /**@snippet [Adding proprietary characteristic to S110 SoftDevice] */
}


/**@brief Function for adding TX characteristic.
 *
 * @param[in] p_nus       Nordic UART Service structure.
 * @param[in] p_nus_init  Information needed to initialize the service.
 *
 * @return NRF_SUCCESS on success, otherwise an error code.
 */
static uint32_t tx_char_add(ble_nus_t * p_nus, const ble_nus_init_t * p_nus_init)
{
    ble_gatts_char_md_t char_md;
    ble_gatts_attr_t    attr_char_value;
    ble_uuid_t          ble_uuid;
    ble_gatts_attr_md_t attr_md;

    memset(&char_md, 0, sizeof(char_md));

    char_md.char_props.write         = 1;
    char_md.char_props.write_wo_resp = 1;
    char_md.p_char_user_desc         = NULL;
    char_md.p_char_pf                = NULL;
    char_md.p_user_desc_md           = NULL;
    char_md.p_cccd_md                = NULL;
    char_md.p_sccd_md                = NULL;

    ble_uuid.type = p_nus->uuid_type;
    ble_uuid.uuid = BLE_UUID_NUS_TX_CHARACTERISTIC;

    memset(&attr_md, 0, sizeof(attr_md));

    BLE_GAP_CONN_SEC_MODE_SET_OPEN(&attr_md.read_perm);
    BLE_GAP_CONN_SEC_MODE_SET_OPEN(&attr_md.write_perm);

    attr_md.vloc    = BLE_GATTS_VLOC_STACK;
    attr_md.rd_auth = 0;
    attr_md.wr_auth = 0;
    attr_md.vlen    = 1;

    memset(&attr_char_value, 0, sizeof(attr_char_value));

    attr_char_value.p_uuid    = &ble_uuid;
    attr_char_value.p_attr_md = &attr_md;
    attr_char_value.init_len  = 1;
    attr_char_value.init_offs = 0;
    attr_char_value.max_len   = BLE_NUS_MAX_TX_CHAR_LEN;

    return sd_ble_gatts_characteristic_add(p_nus->service_handle,
                                           &char_md,
                                           &attr_char_value,
                                           &p_nus->tx_handles);
}
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
